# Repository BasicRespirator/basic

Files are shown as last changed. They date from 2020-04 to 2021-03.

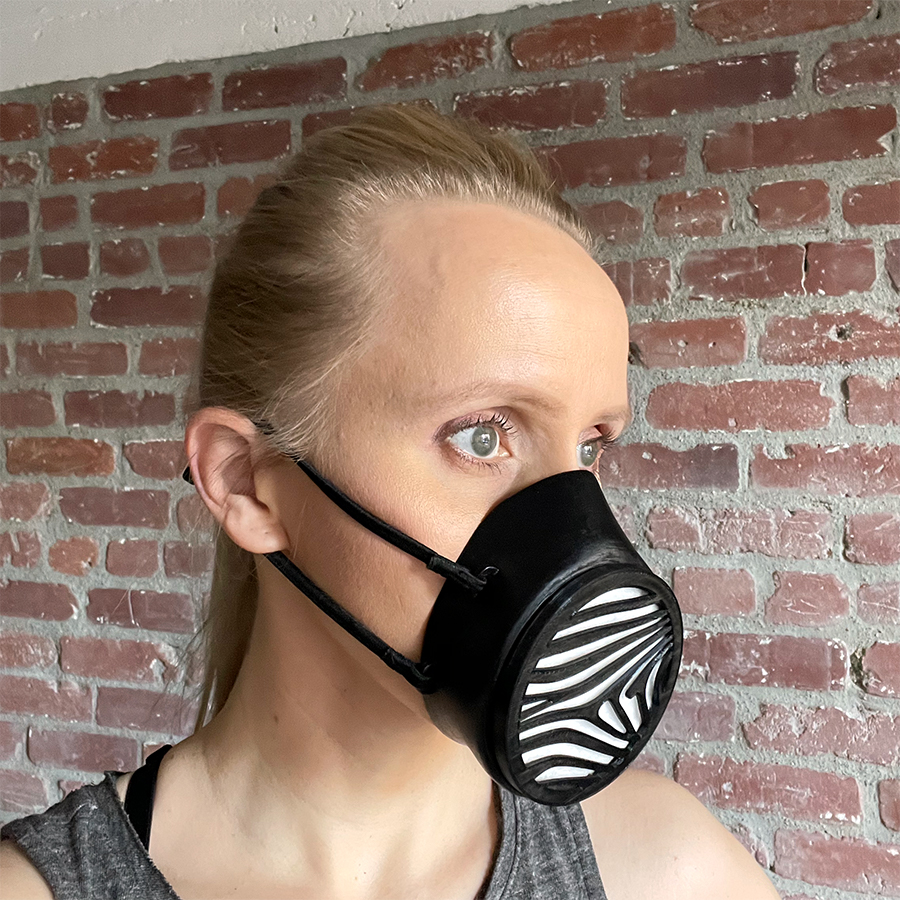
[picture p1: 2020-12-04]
3d printed mask/photos/3d printed square.jpg

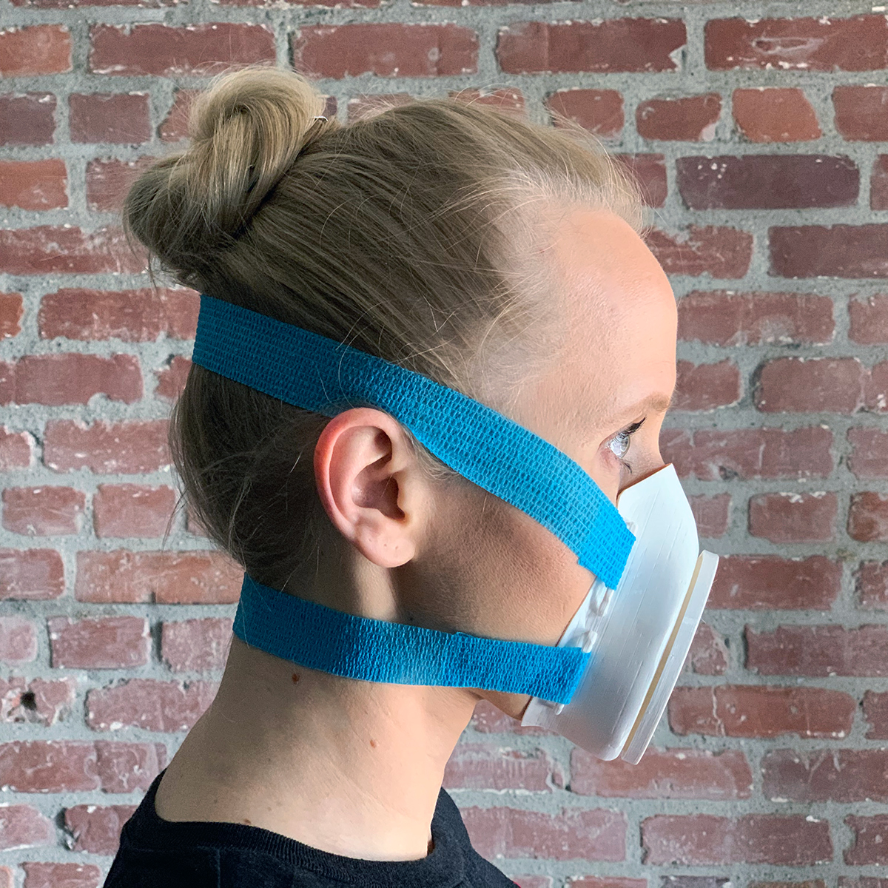
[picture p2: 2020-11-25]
3d printed mask/photos/mask side.jpg

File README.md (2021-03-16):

# basic
All files and descriptions within this repo are patent pending.

Basic Respirator comes in 3 versions 

1: Reusable 3D printable</br>
2: Reusable cut & sew from water repellant ballistic nylon fabric with 3D printed filter assembly</br>
3: Disposable cut & fold from Tyvek 1073B with 3D printed filter assembly</br>

All versions accept a standard 3 1/8" N95 disc filter manufactured by Honeywell or Moldex. Neoprene is used for the seal against the face and to prevent leakage through the filter assembly. 

The cut & sew version is more complicated to make, but can be produced with a heavy duty home sewing machine. Tyvek can be printed on an inket printer and many double-sided adhesives are available. 

This is intended to be a surgical N95 respirator, but may not meet regulations. Some coated fabrics contain carcinogens that are dangerous to inhale. The design for the filter assembly will likely need to be modified to increase the surface area and slow airflow. I have released the design as-is and will continue modifications. 

DISCLAIMER
This design is a work in progress and not NIOSH certified or FDA approved. Please use your best judgement and discretion before wearing this mask and observe the guidelines recommended by the CDC and public health departments. We do not claim that this mask is guaranteed to keep you protected from COVID-19.

Feel free to email me with questions at basicrespirator@gmail.com and/or I can add you to the mailing list for updates. 

LICENSE

<br />Basic Respirator by Hunter Futo of Electric Church, Inc. is licensed under a <a rel="license" href="http://creativecommons.org/licenses/by-nc-nd/4.0/">Creative Commons Attribution-NonCommercial-NoDerivatives 4.0 International License</a>.

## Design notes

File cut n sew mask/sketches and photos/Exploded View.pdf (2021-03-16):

# Basic Respirator Cut & Sew v5.0

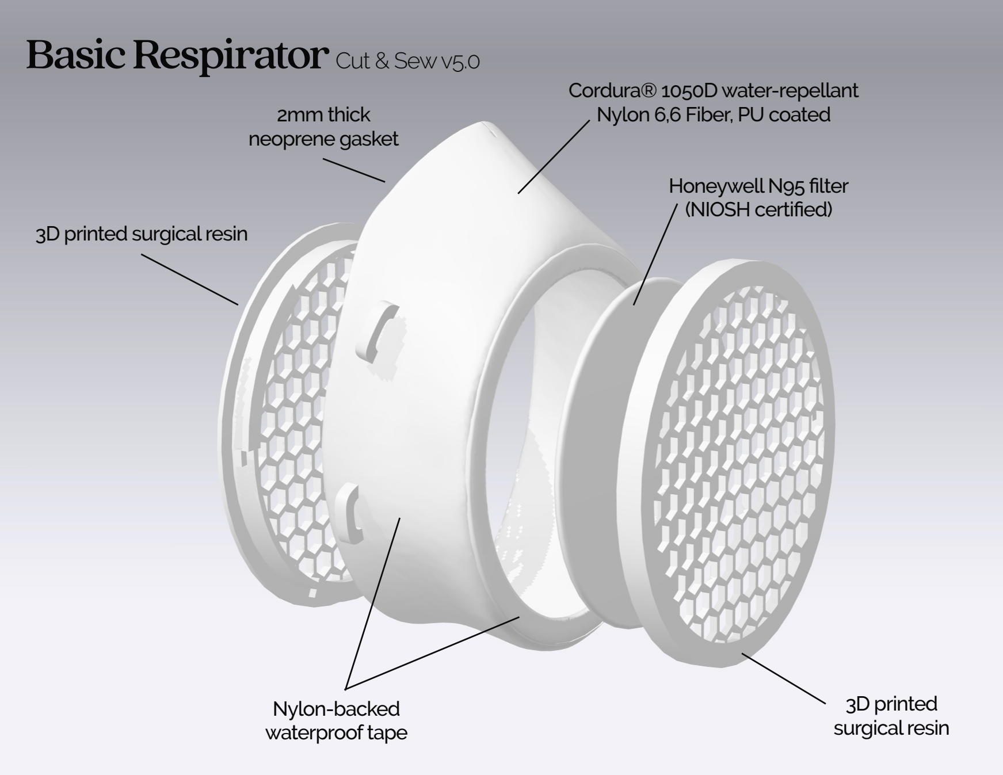
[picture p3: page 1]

3D printed surgical resin

Honeywell N95 filter
(NIOSH certified)

Nylon-backed
waterproof tape

Cordura® 1050D water-repellant
2mm thick | Nylon 6,6 Fiber, PU coated
neoprene gasket

3D printed
surgical resin

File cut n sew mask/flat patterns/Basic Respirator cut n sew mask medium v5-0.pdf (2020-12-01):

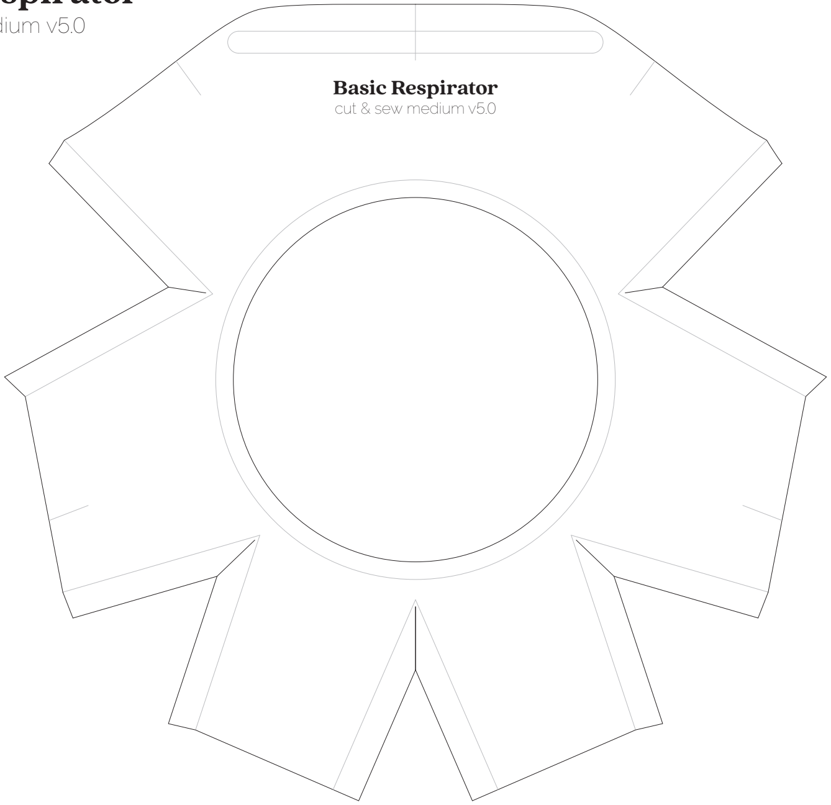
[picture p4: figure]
Basic Respirator cut & sew medium v5.0

Basic Respirator by Hunter Futo / Electric Church, Inc. is licensed under a Creative Commons Attribution 4.0 International License

# Basic Respirator

## cut & sew medium v5.0

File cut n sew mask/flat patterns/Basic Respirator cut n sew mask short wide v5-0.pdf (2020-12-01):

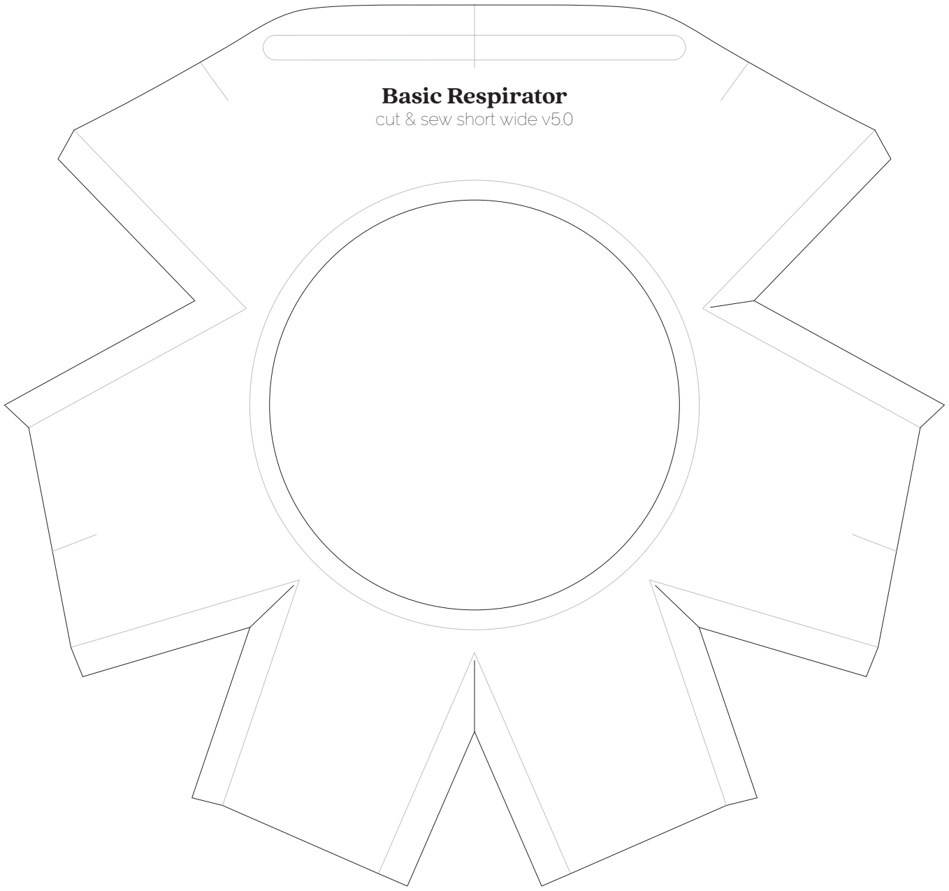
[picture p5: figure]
Basic Respirator cut & sew short wide v5.0

Basic Respirator by Hunter Futo / Electric Church, Inc. is licensed under a Creative Commons Attribution 4.0 International License

# Basic Respirator

## cut & sew short wide v5.0

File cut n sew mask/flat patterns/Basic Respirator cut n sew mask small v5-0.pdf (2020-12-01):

# Basic Respirator

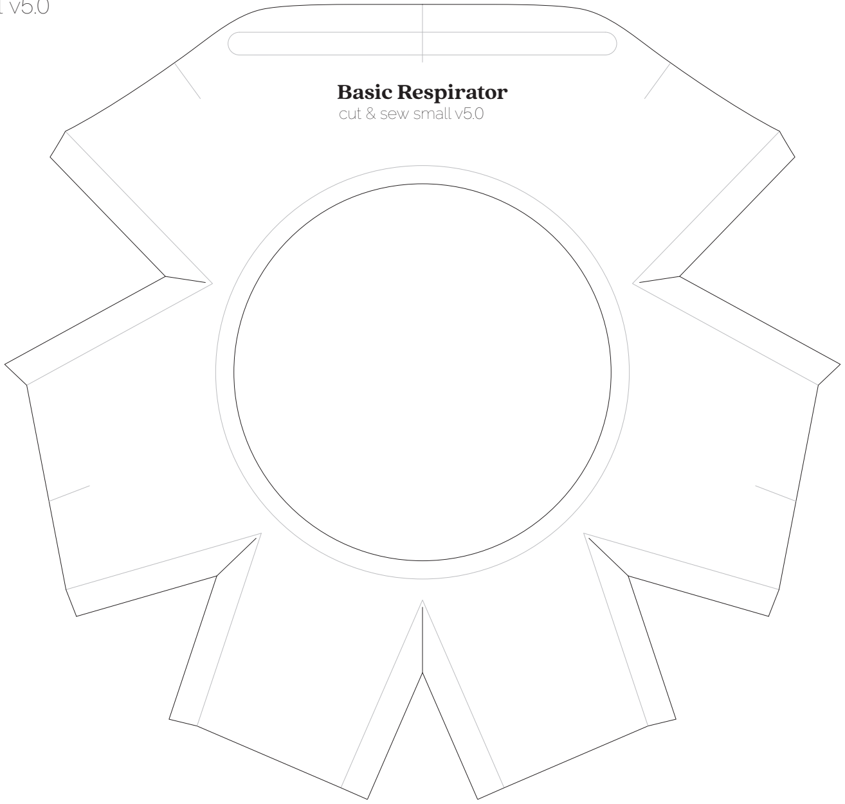
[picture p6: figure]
Basic Respirator cut & sew small v5.0

## cut & sew small v5.0

Basic Respirator by Hunter Futo / Electric Church, Inc. is licensed under a Creative Commons Attribution 4.0 International License

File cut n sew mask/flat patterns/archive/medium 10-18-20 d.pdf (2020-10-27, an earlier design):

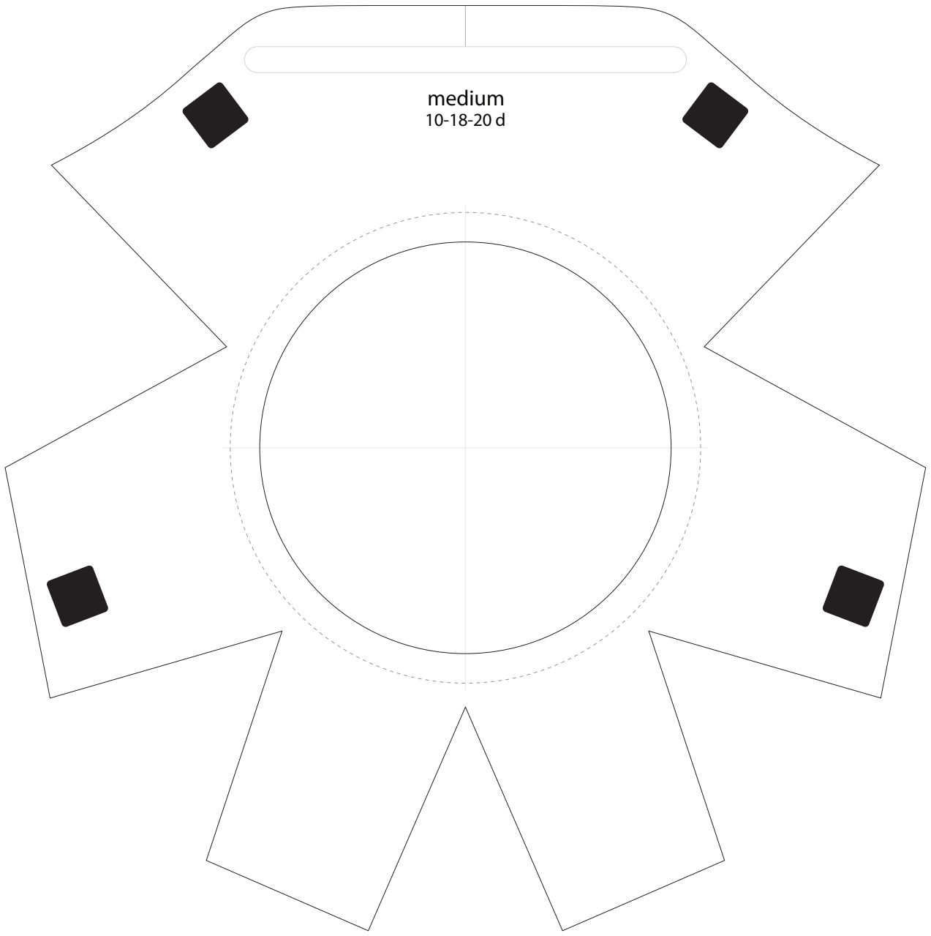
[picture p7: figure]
medium 10-18-20 d

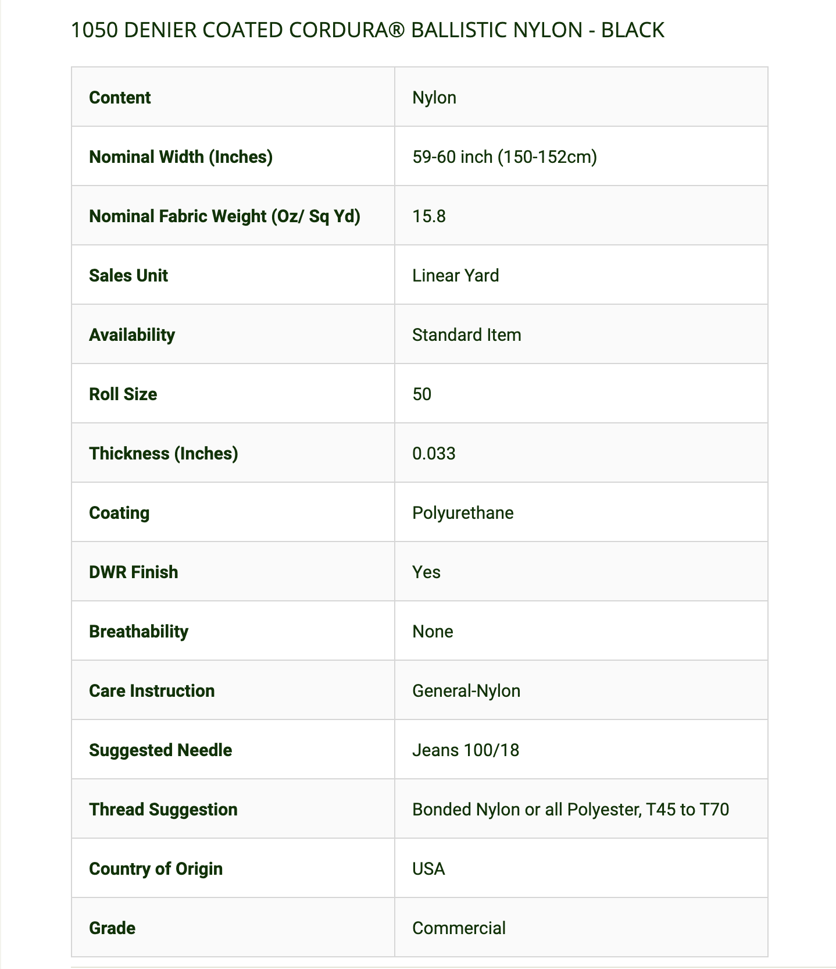
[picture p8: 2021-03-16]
documents/Material Data Sheets/Cordura 1050D product specifications.png

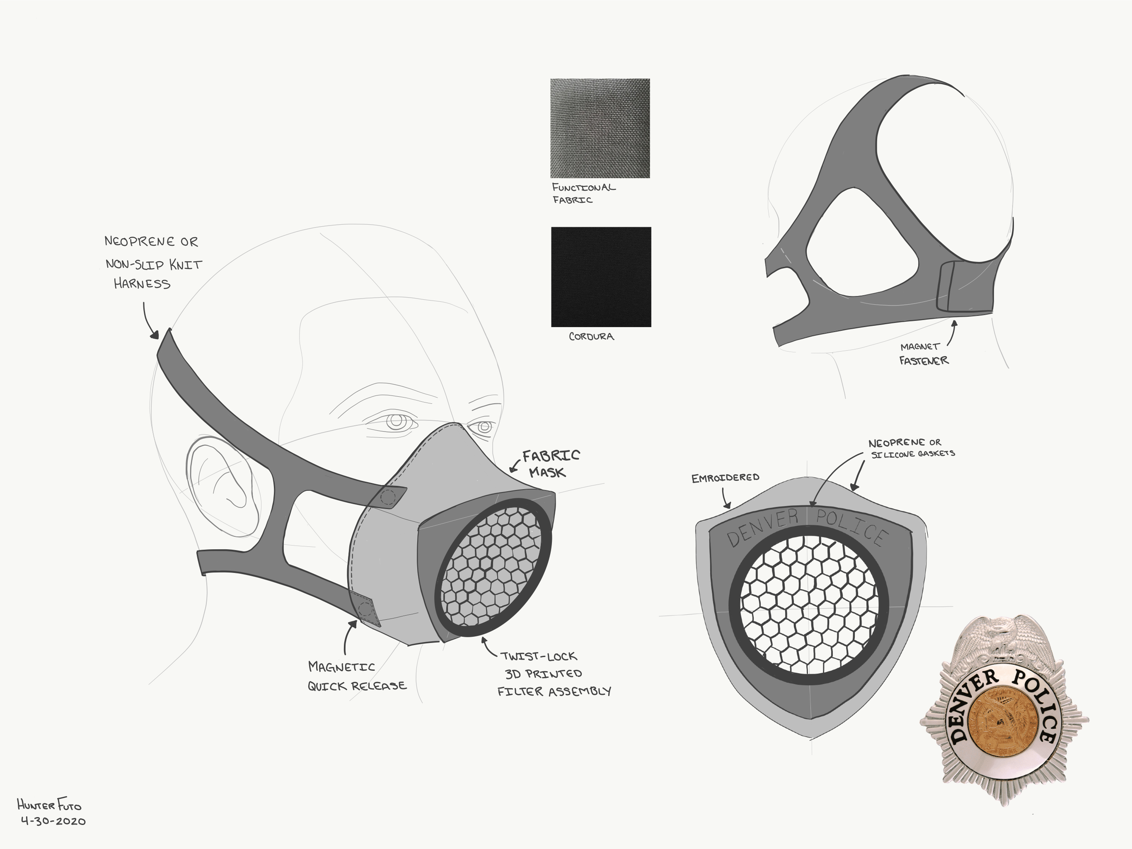
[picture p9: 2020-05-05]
reusable_mask/sketches and photos/reusable respirator concept.png

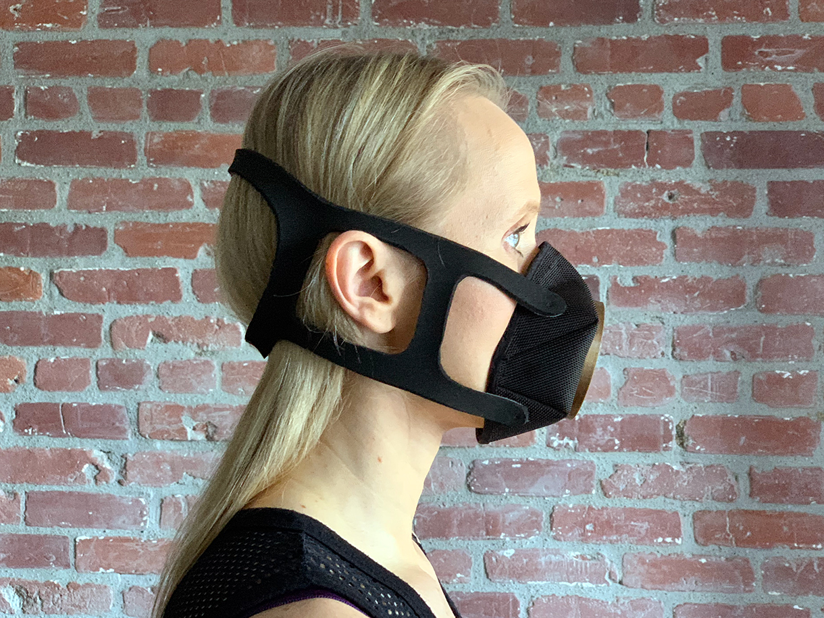
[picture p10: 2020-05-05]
reusable_mask/sketches and photos/profile.jpg

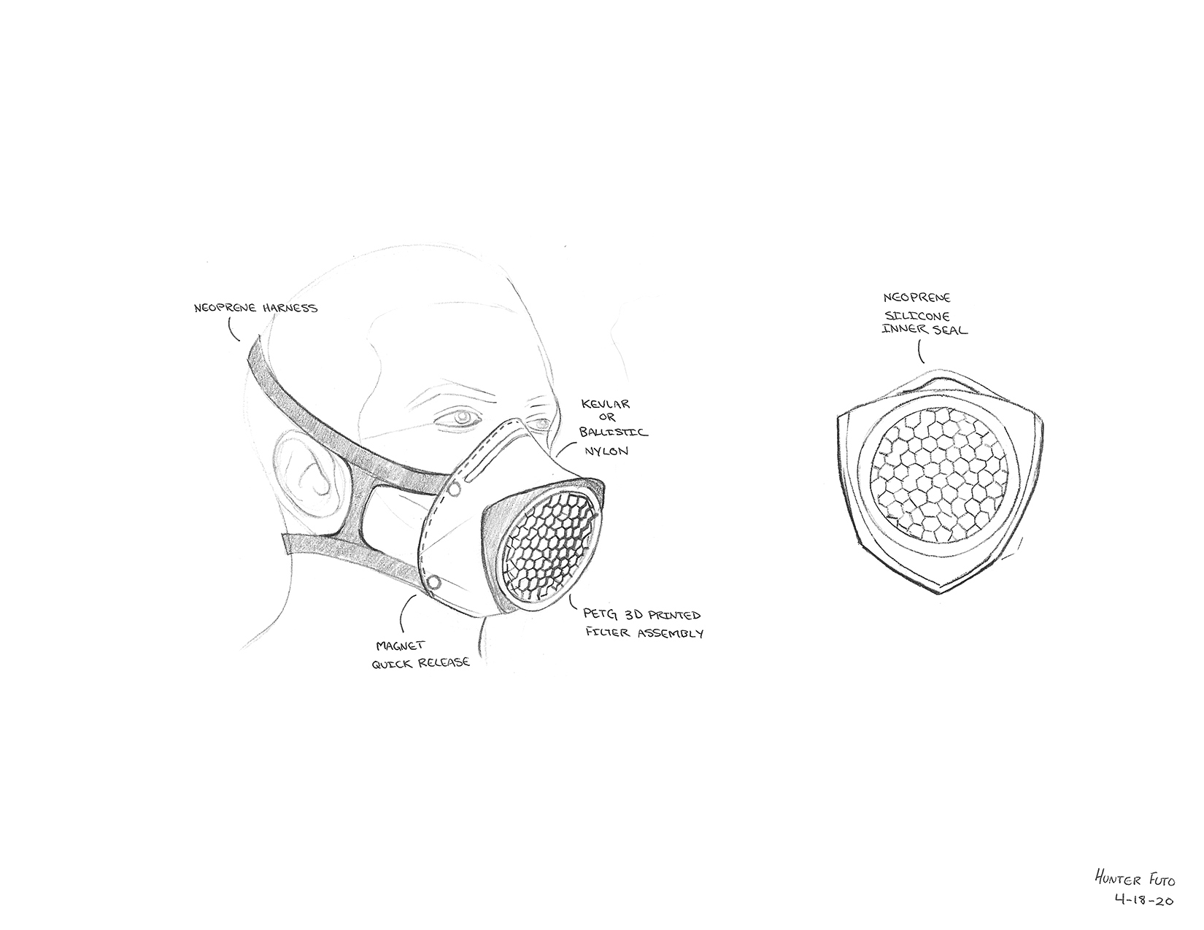
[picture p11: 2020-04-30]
reusable_mask/sketches and photos/sketch041820.jpg

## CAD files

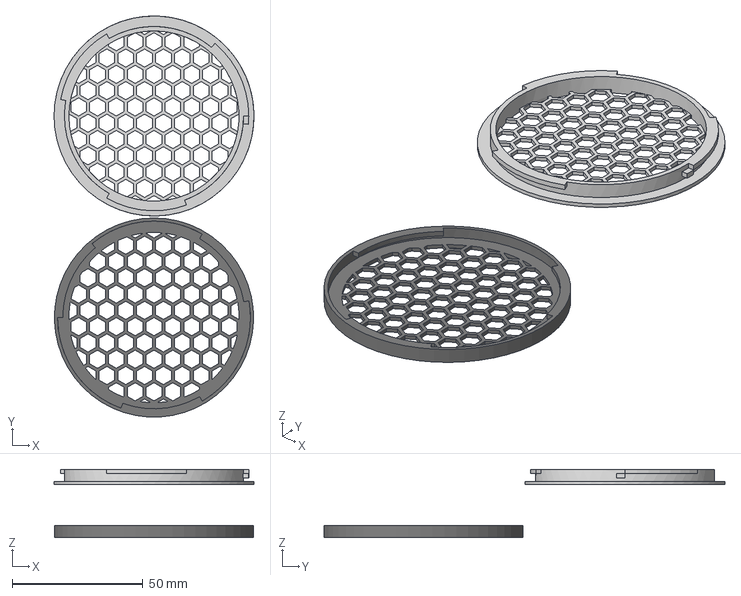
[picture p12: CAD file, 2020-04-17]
prior versions/65mm Filter Assembly/filter_assembly_65mm_slim.step
76.4 x 153.2 x 26.0 mm
Honeycomb Cap
Honeycomb Holder: Neoprene Gasket

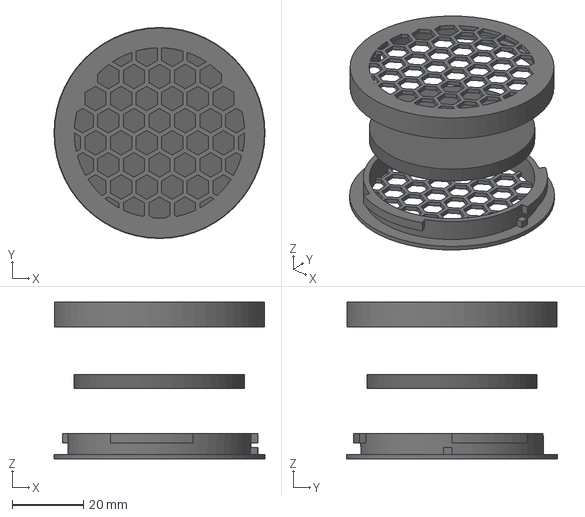
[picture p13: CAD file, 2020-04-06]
prior versions/48mm Filter Assembly/BasicRespiratorFilterAssembly48mm.step
59.4 x 59.4 x 44.1 mm
Honeycomb Holder
Honeycomb Cap

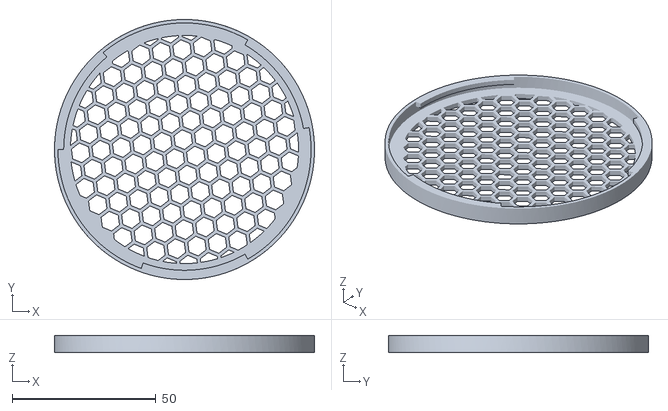
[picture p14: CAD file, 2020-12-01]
3125 inch Filter Assembly/honeycomb_cap-thin.stl
90.5 x 90.5 x 6.00

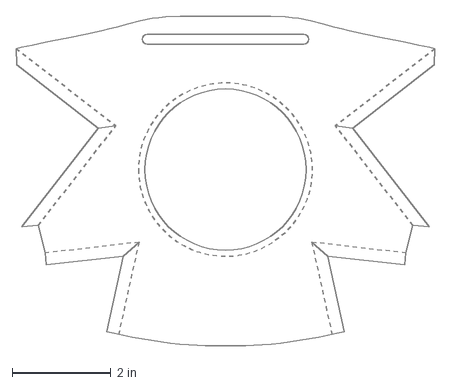
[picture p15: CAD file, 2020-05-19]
cut n sew mask/prior versions/reusable_medium_5-18.dxf
8.46 x 6.67 in

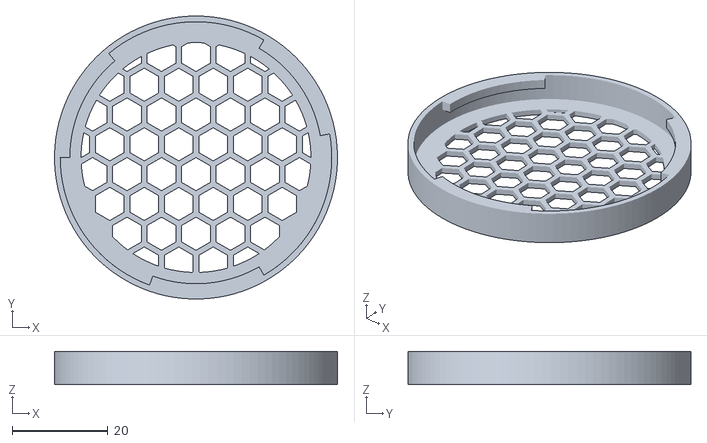
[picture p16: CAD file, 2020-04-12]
prior versions/48mm Filter Assembly/FilterCap48mm.stl
59.1 x 59.1 x 6.95

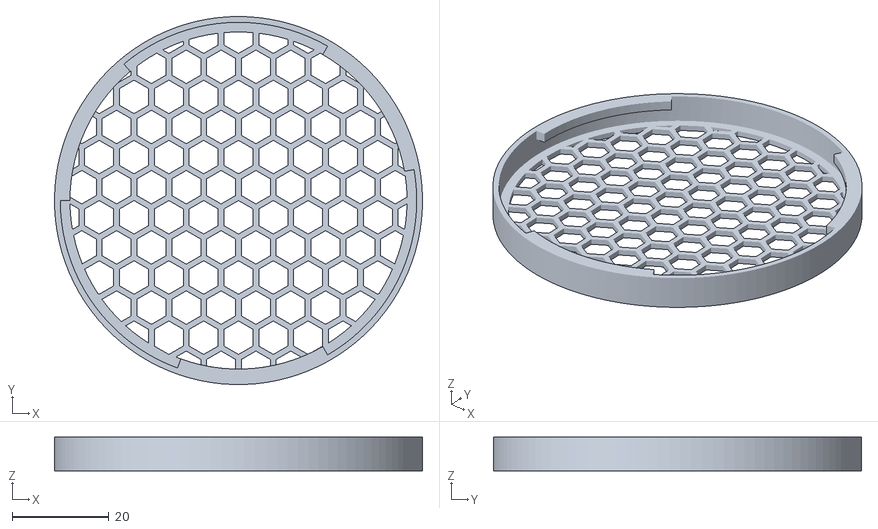
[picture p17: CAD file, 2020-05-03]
prior versions/65mm Filter Assembly/filter_cap_65_easier_to_grab.stl
76.1 x 76.1 x 6.95

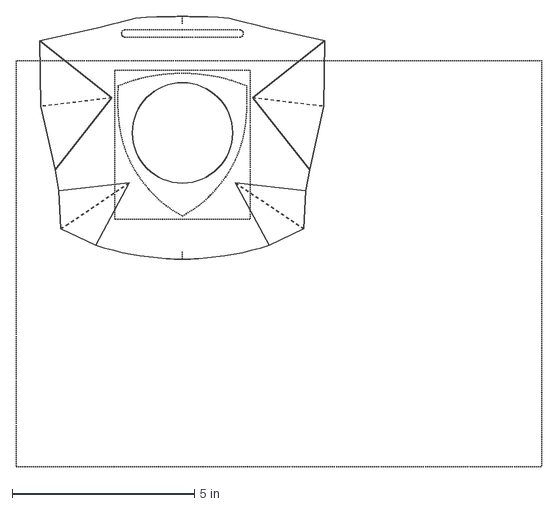
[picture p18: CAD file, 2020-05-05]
reusable_mask/mask_large.dxf
14.4 x 12.4 in

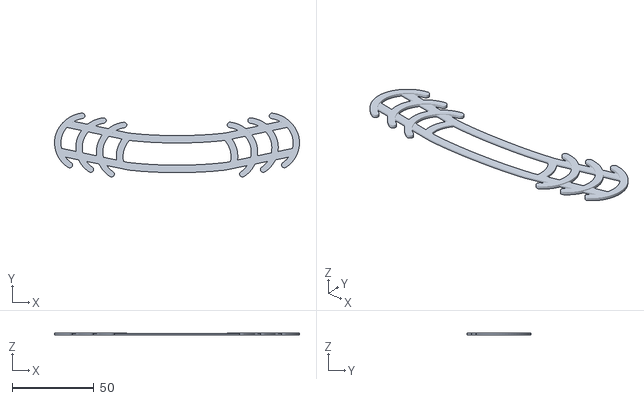
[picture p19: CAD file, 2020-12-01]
strap clips/ear saver.stl
150.0 x 39.1 x 1.50

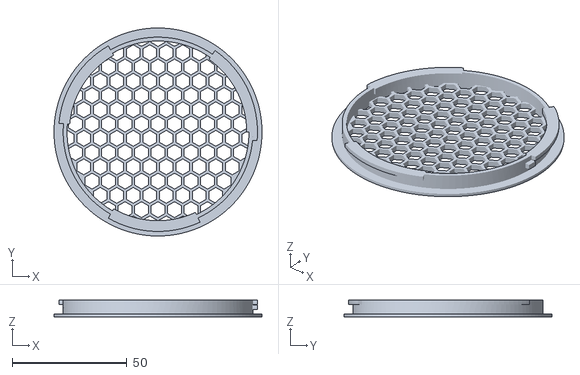
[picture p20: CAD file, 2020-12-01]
3125 inch Filter Assembly/Filter holder standard size with tolerance.stl
90.8 x 90.8 x 7.20

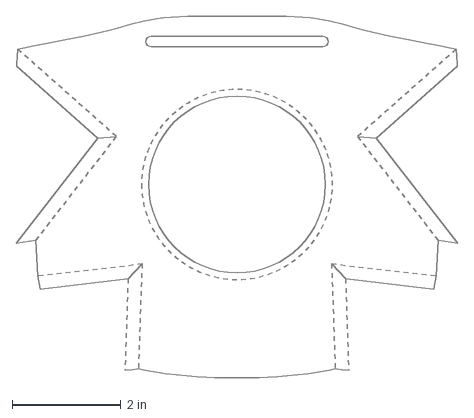
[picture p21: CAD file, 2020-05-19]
cut n sew mask/prior versions/reusable_small_5-18.dxf
8.13 x 6.67 in

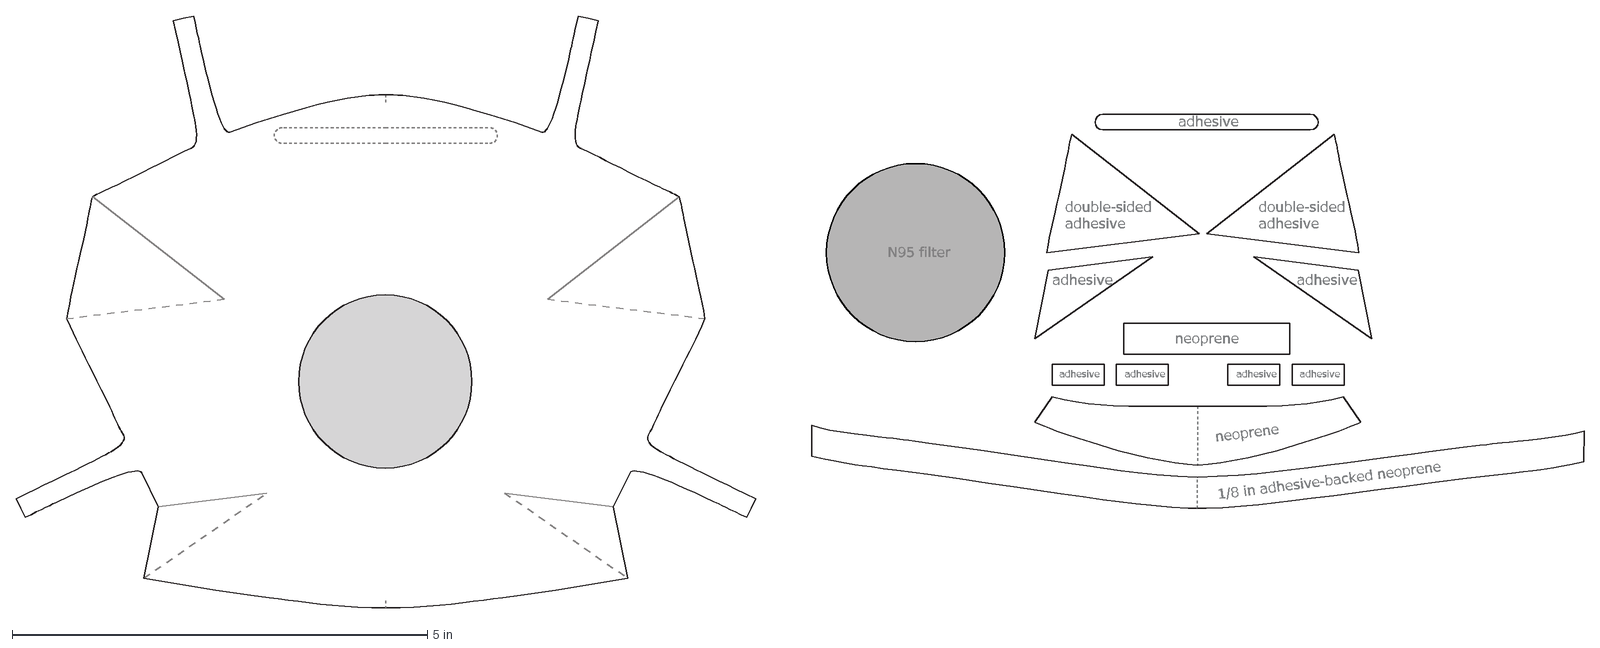
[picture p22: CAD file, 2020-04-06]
prior versions/48mm Filter Assembly/BasicRespiratorFlatPatternMedium.dxf
1/8 in adhesive-backed neoprene
neoprene
double-sided
adhesive
N95 filter

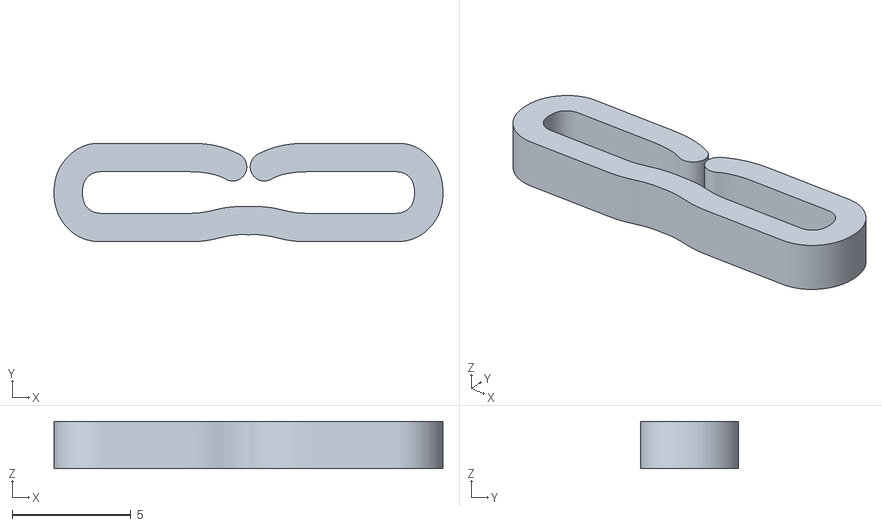
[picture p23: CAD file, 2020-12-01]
strap clips/strap clip.stl
16.4 x 4.15 x 2.00

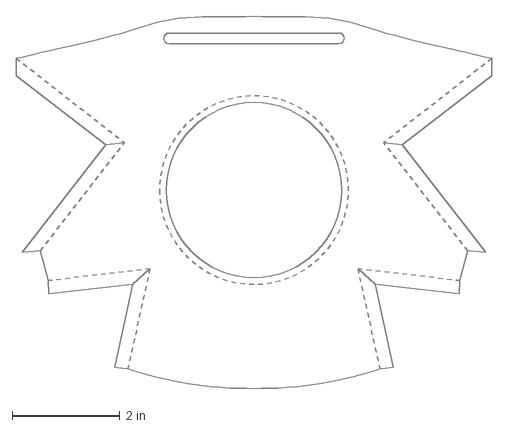
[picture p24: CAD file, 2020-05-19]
cut n sew mask/prior versions/reusable_large_5-18.dxf
8.84 x 6.92 in

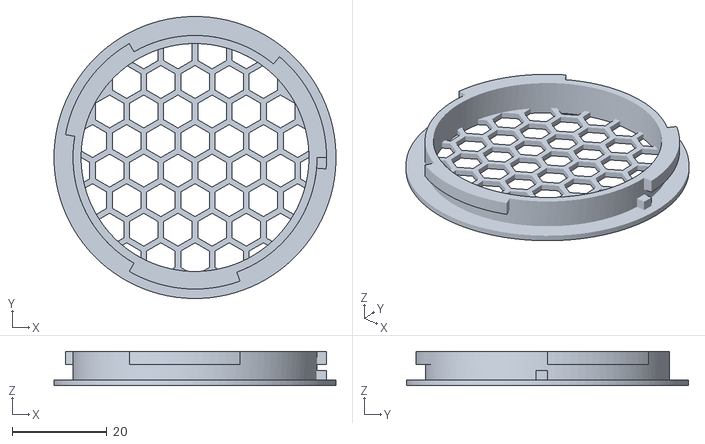
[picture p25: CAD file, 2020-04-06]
prior versions/48mm Filter Assembly/FilterHolder48mm.stl
59.4 x 59.4 x 7.20

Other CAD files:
disposable tyvek mask/BasicRespiratorFlatPatternLarge.dxf
prior versions/65mm Filter Assembly/filter_cap_65_slim.stl
cut n sew mask/prior versions/harness_5-4.dxf
prior versions/65mm Filter Assembly/filter_holder_65_slim.stl

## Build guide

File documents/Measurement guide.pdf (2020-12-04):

# Measurement Guide

## reusable v 1.0

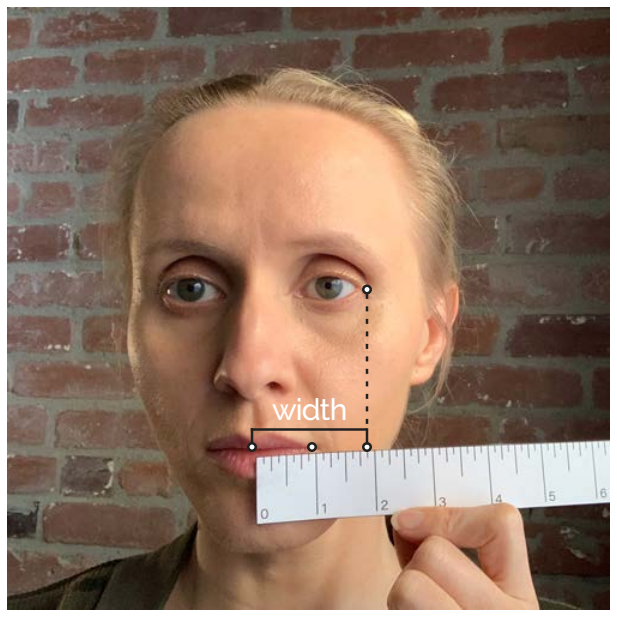
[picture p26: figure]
width

small
short wide
medium
long narrow
large

1 7/8 in ( 4.75 cm )
2 1/8 in ( 5.50 cm )
2 3/8 in ( 6.00 cm )
2 1/4 in ( 5.75 cm )
2 1/2 in ( 6.25 cm )

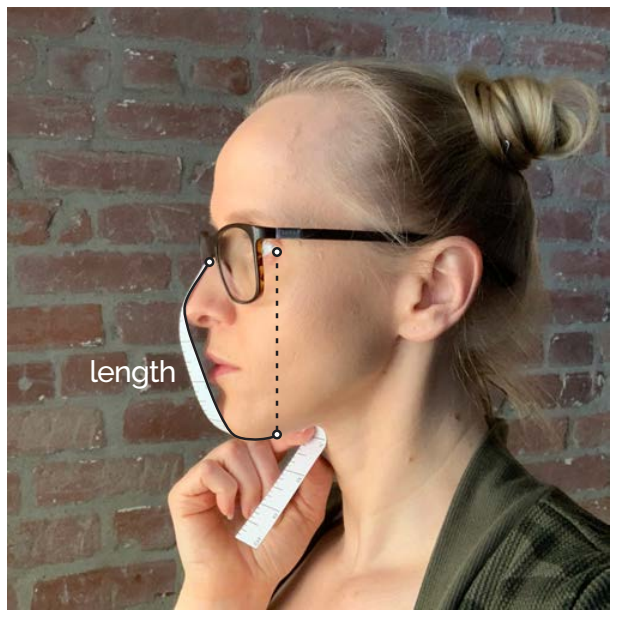
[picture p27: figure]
length

small
short wide
medium
long narrow
large

5 1/4 in ( 13.25 cm )
5 1/8 in ( 13.00 cm )
5 3/8 in ( 13.75 cm )
5 5/8 in ( 14.25 cm )
6 in ( 15.25 cm )

# Instructions

1. Print page and cut out ruler with scissors. Check it against an actual ruler to ensure it printed correctly.
2. Keep this paper handy to check off your measurements.
3. Measure the width from the center of your mouth to the outside corner plus at least 1 inch. This will be the mask width so find a comfortable distance.
4. Measure the height from the bridge of your nose to underneath your chin. If you need a guide, use the outside edge of your eye. If you wear glasses, measure just below them.
5. Select your size based on these measurements and the reference images. If you are not sure, use your measured length.
width | length

# NIOSH sizes

## reusable v 1.0

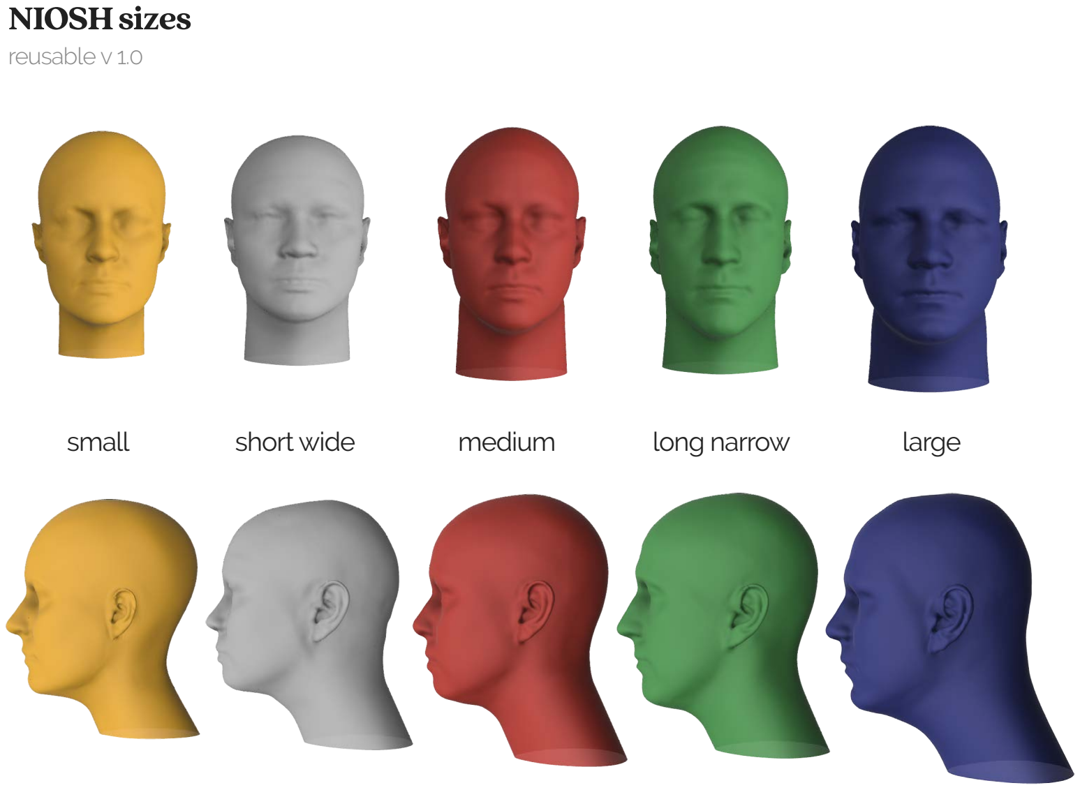
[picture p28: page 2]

small | short wide | medium | long narrow | large

# Customization

## reusable v 1.0

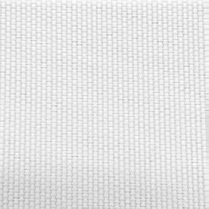
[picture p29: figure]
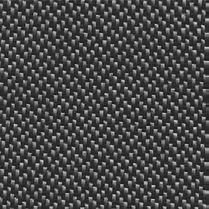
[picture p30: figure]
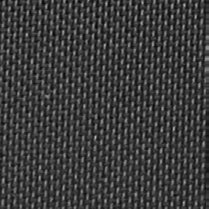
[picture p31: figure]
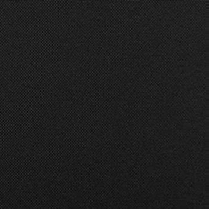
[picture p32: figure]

white | silver/black | graphite | black

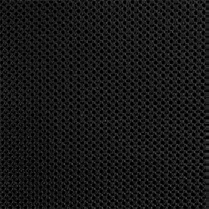
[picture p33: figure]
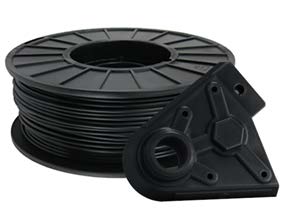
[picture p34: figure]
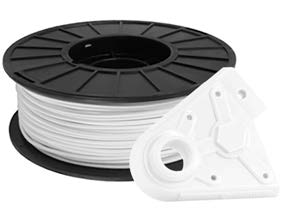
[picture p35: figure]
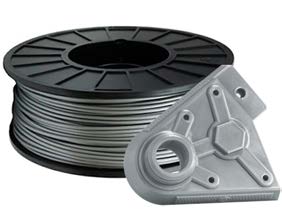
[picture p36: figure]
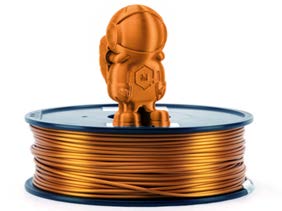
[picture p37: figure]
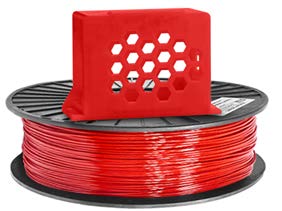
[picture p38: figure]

black | white | silver | copper | red

### black

mask | harness

## filter assembly

# Reference Images

## reusable v 1.0

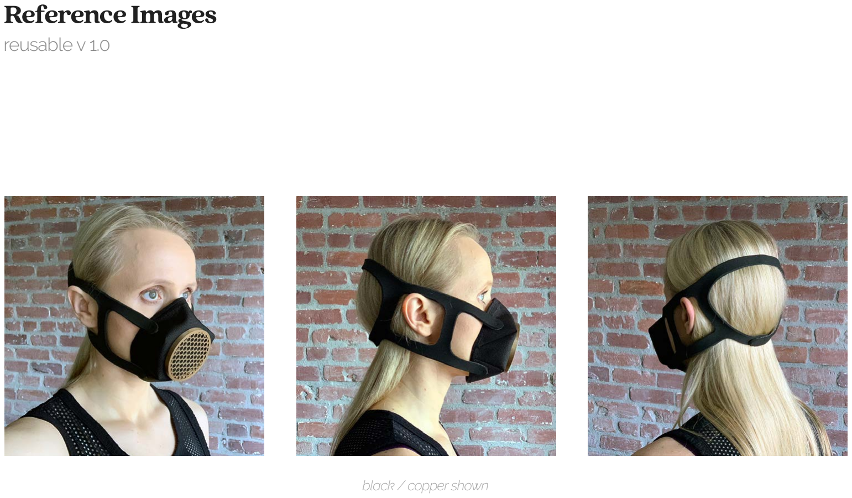
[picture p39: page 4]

black / copper shown

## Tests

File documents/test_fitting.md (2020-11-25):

# basic
TEST FITTING INSTRUCTIONS

placeholder for now

LICENSE

Shield: [][cc-by-sa]

Basic Respirator by Hunter Futo of Electric Church Inc. is licensed under a [Creative Commons Attribution-ShareAlike 4.0 International License][cc-by-sa].

[][cc-by-sa]

[cc-by-sa]: http://creativecommons.org/licenses/by-sa/4.0/
[cc-by-sa-image]: https://licensebuttons.net/l/by-sa/4.0/88x31.png
[cc-by-sa-shield]: https://img.shields.io/badge/License-CC%20BY--SA%204.0-lightgrey.svg

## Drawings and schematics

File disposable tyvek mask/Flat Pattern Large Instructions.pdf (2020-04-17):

# Basic Respirator

### large disposable mask v0.95

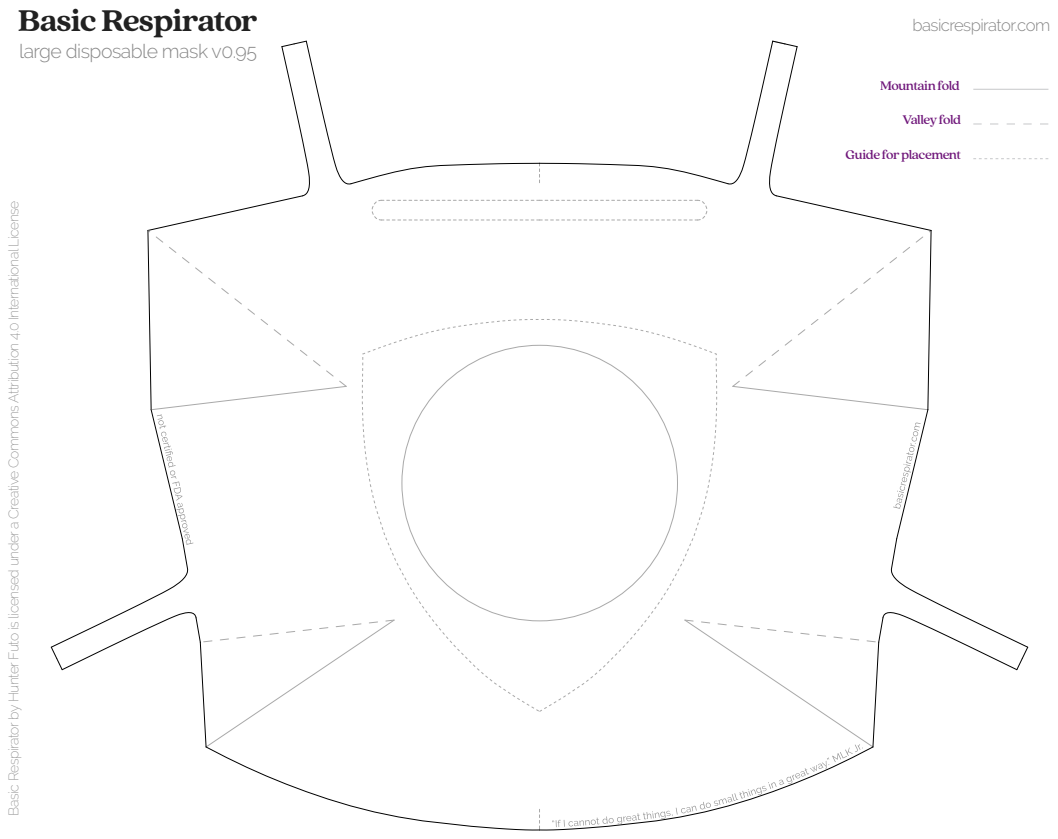
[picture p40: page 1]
basicrespirator.com; Mountain fold; Valley fold

Guide for placement

Basic Respirator by Hunter Futo is licensed under a Creative Commons Attribution 4.0 International License

# Basic Respirator

### large disposable mask v0.95

basicrespirator.com

# Instructions

1. Print, lasercut or trace mask onto Tyvek™.
2. Lasercut or trace seal and shield gasket from neoprene and cut.
3. Print, lasercut or trace adhesive and cut.
4. Trace pattern onto filter material and cut
5. Peel & stick adhesive, neoprene shield gasket and nosepiece onto mask. Cut center hole.
6. Pre-fold mask on gray lines where indicated.
7. Peel off paper backing and fold mask.
8. Peel and stick neoprene seal along inside edge.
9. Try on mask and mold nosipiece.
10. Add strips of extra neoprene where there are gaps.
11. Pop in 3D printed filter enclosure and add precut filter.

large upper seal
1/8 in. neoprene

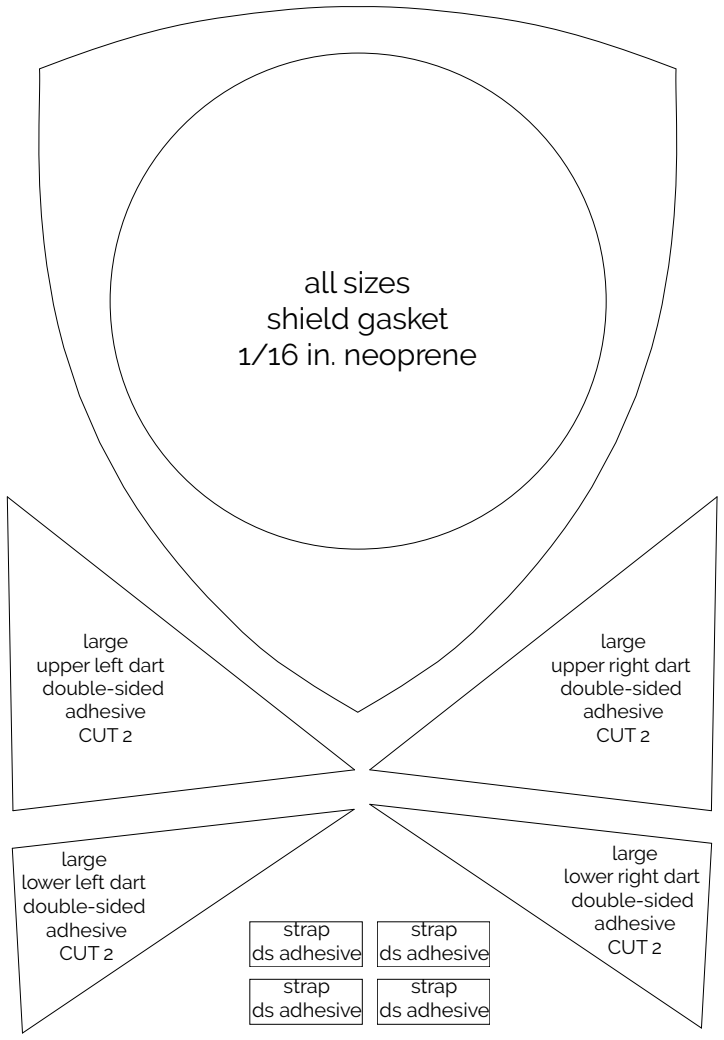
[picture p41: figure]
all sizes shield gasket 1/16 in. neoprene; large upper left dart double-sided adhesive CUT 2; large lower left dart double-sided adhesive CUT 2; large lower right dart double-sided adhesive CUT 2; large upper right dart double-sided adhesive CUT 2; strap ds adhesive; strap ds adhesive strap ds adhesive

all sizes 85mm nosepiece double-sided adhesive

Basic Respirator by Hunter Futo is licensed under a Creative Commons Attribution 4.0 International License

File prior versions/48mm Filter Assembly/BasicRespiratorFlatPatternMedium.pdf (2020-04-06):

Basic Respirator disposable mask with filter assembly v0.9 | basicrespirator.com

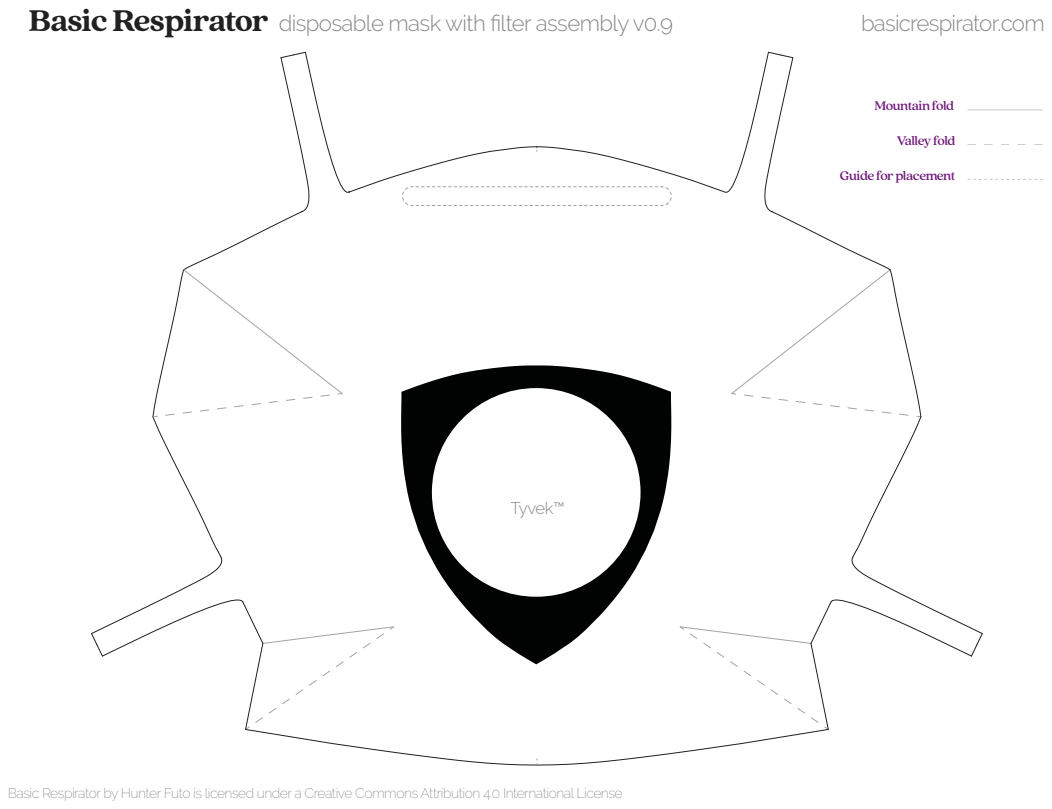
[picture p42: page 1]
Mountain fold; Valley fold; Tyvek™

Guide for placement

Basic Respirator by Hunter Futo is licensed under a Creative Commons Attribution 4.0 International License

# Basic Respirator

# Instructions

## disposable mask with filter assembly v0.9

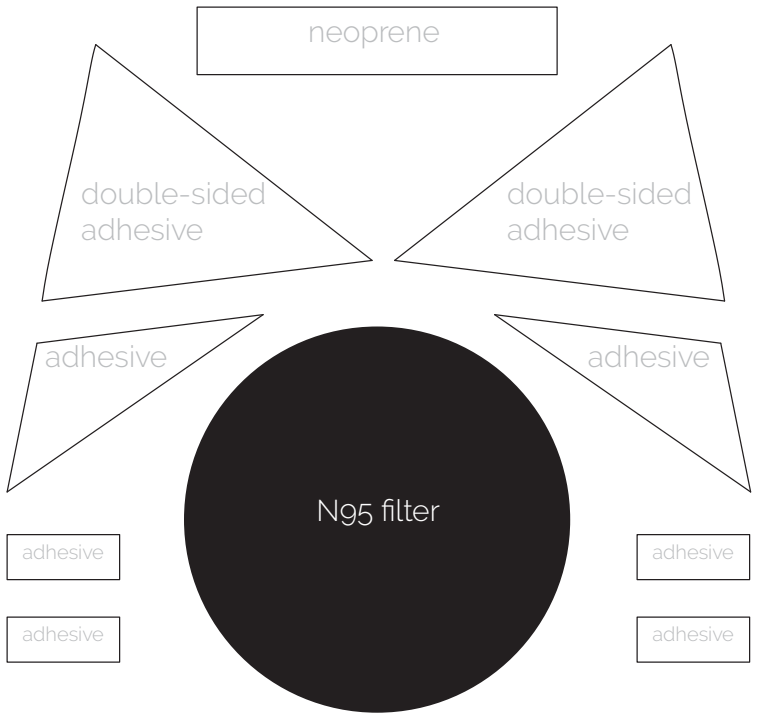
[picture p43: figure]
N95 filter; double-sided adhesive; adhesive; neoprene

1 Print or trace mask onto Tyvek™ and cut center hole

2 Pre-fold mask on gray lines where indicated

3 Cut out shapes on solid black lines

4 Trace smaller pieces onto materials and cut

5 Peel & stick adhesive and nosepiece onto mask

6 Peel off paper backing and fold mask

7 Peel and stick seal along inside edge

8 Try on mask and mold nosipiece

9 Add strips of extra neoprene where there are gaps

10 Pop in 3D printed filter enclosure and add filter

## basicrespirator.com

adhesive

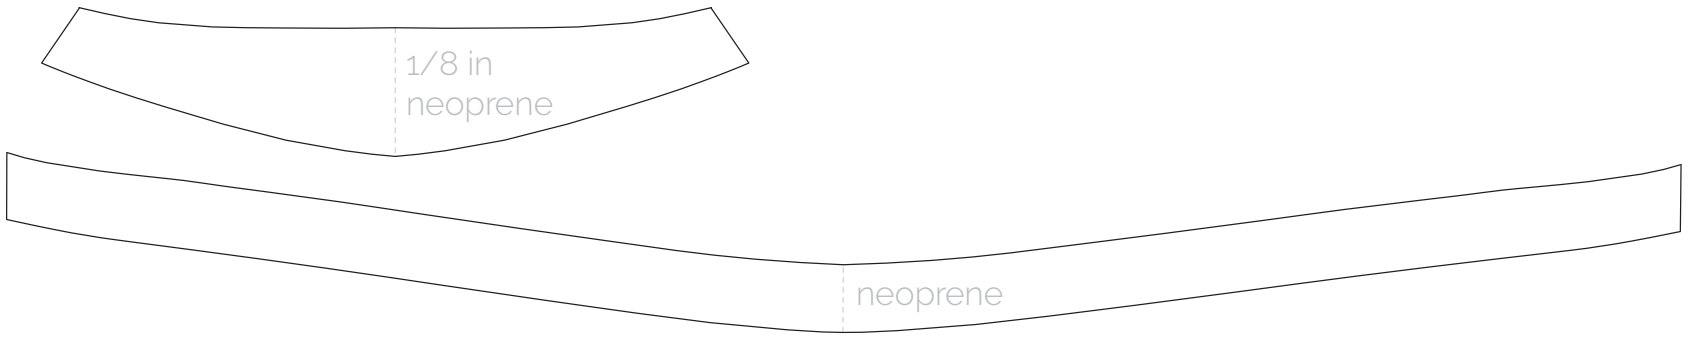
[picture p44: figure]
1/8 in neoprene; neoprene

Basic Respirator by Hunter Futo is licensed under a Creative Commons Attribution 4.0 International License

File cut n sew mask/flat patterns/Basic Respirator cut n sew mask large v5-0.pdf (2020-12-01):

# Basic Respirator

## cut & sew large v5.0

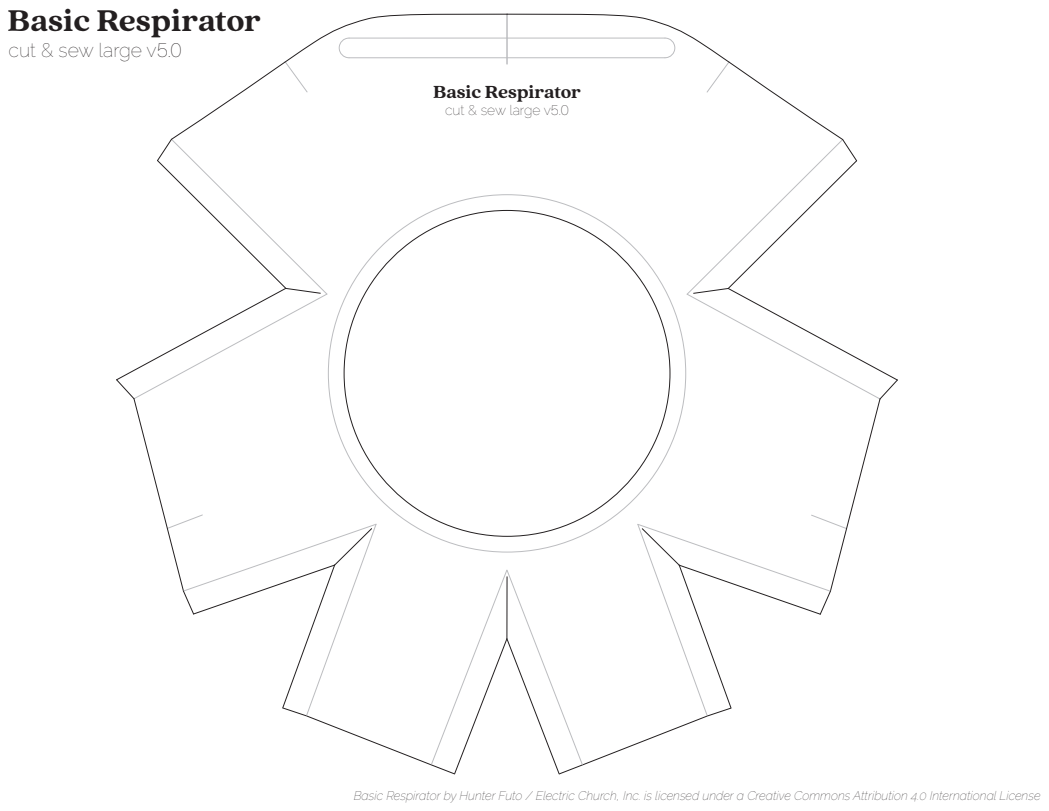
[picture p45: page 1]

Basic Respirator
cut & sew large v5.0

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

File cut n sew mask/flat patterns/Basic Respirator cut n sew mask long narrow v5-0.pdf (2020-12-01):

# Basic Respirator

## cut & sew long narrow v5.0

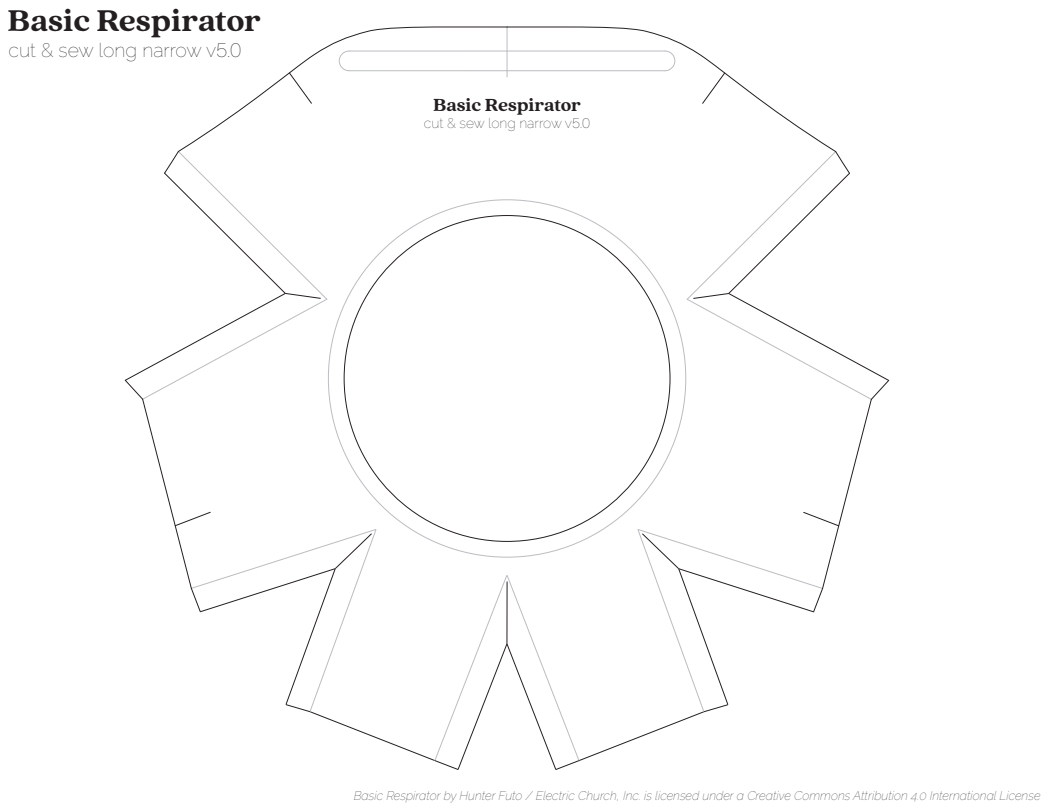
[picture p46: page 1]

Basic Respirator
cut & sew long narrow v5.0

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

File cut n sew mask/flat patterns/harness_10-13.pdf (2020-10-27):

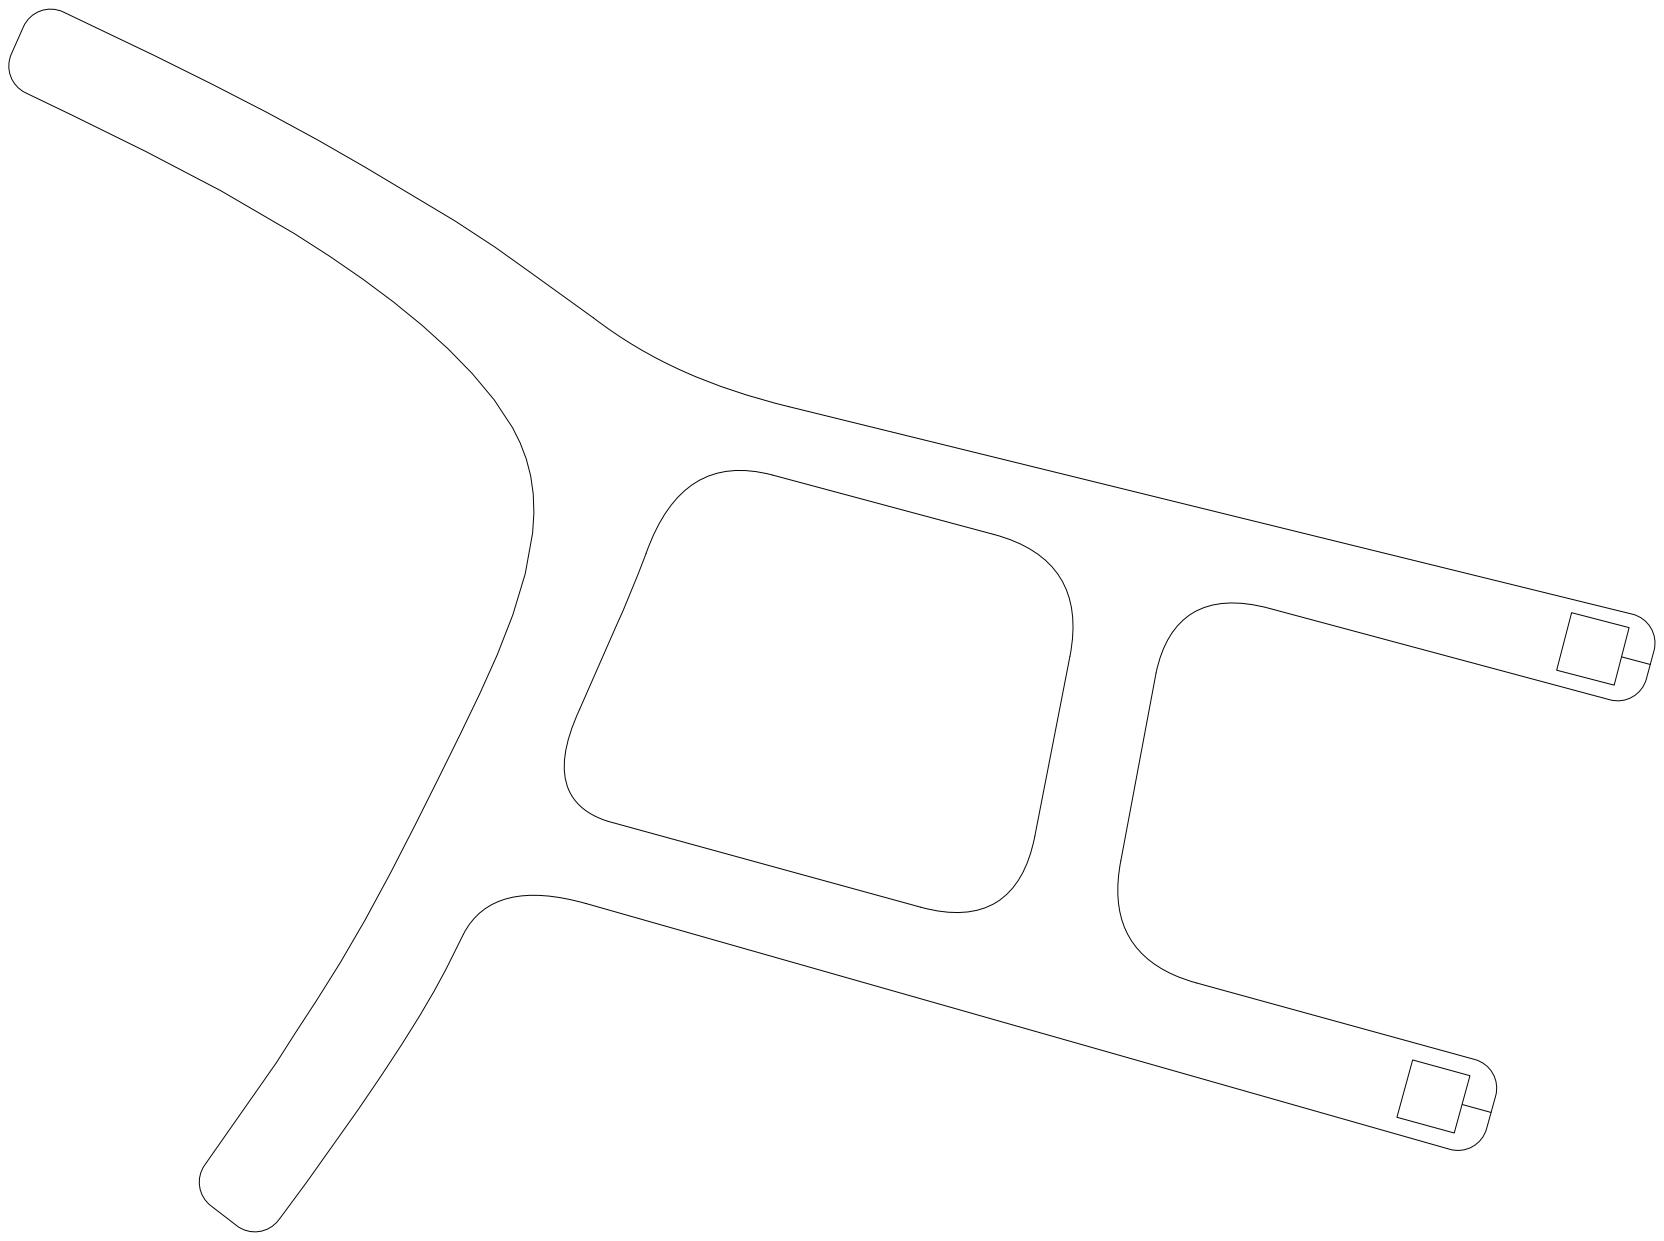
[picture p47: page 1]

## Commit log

2020-04-06 add flat pattern and CAD
    here we go...
    [BasicRespiratorFilterAssembly.step, BasicRespiratorFlatPattern.dxf, FilterCap.stl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]
2020-04-12 replace filter cap stl
    it was upside down
    [FilterCap.stl]
2020-04-17 larger mask size and 65mm filter
    [BasicRespiratorFilterAssembly48mm.step, BasicRespiratorFlatPatternLarge.dxf, BasicRespiratorFlatPatternMedium.dxf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]
2020-04-17 add pdf of flat pattern for 65mm filter
2020-05-03 add easier to grab filter cap
    [filter_cap_65_easier_to_grab.stl]
2020-05-05 upload mask patterns for reusable version
    [BasicRespiratorFilterAssembly48mm.step, BasicRespiratorFlatPatternLarge.dxf, BasicRespiratorFlatPatternMedium.dxf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]
2020-05-19 upload standard sizes
    [harness_5-4.dxf, honeycomb_cap_3125_standard.stl, honeycomb_holder_3125_standard.stl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]
2020-10-27 added 3D printable version of mask, updated flat patterns and reorganized directory
    [BasicRespiratorFilterAssembly48mm.step, BasicRespiratorFlatPatternMedium.dxf, FilterCap48mm.stl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]
2020-10-27 update readme, add photos of 3D printable mask
2020-11-25 new STL for 3D printed mask, medium
    [medium mask with holder 10-25-20 v1.stl]
2020-12-01 updated STL for 3D mask in medium, updated filter assembly, upload cut & sew flat patterns in all 5 sizes
    [BasicRespiratorFilterAssembly48mm.step, BasicRespiratorFlatPatternLarge.dxf, BasicRespiratorFlatPatternMedium.dxf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]
2020-12-06 update readme, add material and safety datasheets

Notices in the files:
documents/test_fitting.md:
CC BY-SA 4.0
